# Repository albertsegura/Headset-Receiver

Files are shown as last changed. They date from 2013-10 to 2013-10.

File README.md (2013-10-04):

Headset-Receiver
================

Custom embedded Arduino board that provides Bluetooth/FM/Jack for a Headphones.
* Bluetooth rn-52 module
* Si4703 FM chip
* Arduino Pro mini 3.3v based board

Repository Contents
-------------------
* **/Eagle Files** - Eagle files for the two boards (.brd, .sch)

OSH PARK
--------
[Headset-Mainboard  
 *Main board*](http://oshpark.com/shared_projects/1vYQ7i1L)

[Headset-Mainboard  
 *Bluetooth Module*](http://oshpark.com/shared_projects/EPMXIzBB)

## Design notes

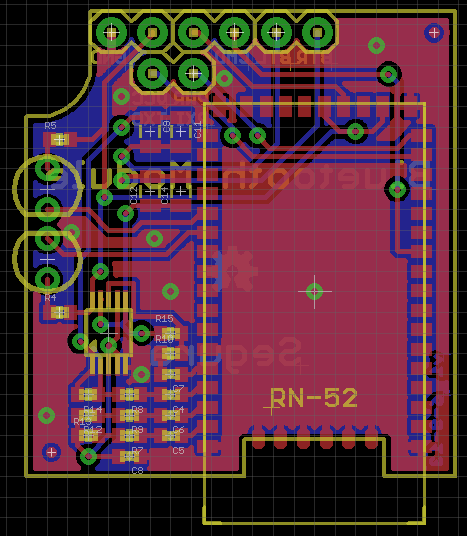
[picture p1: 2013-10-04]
Eagle Files/bluetooth-module.png

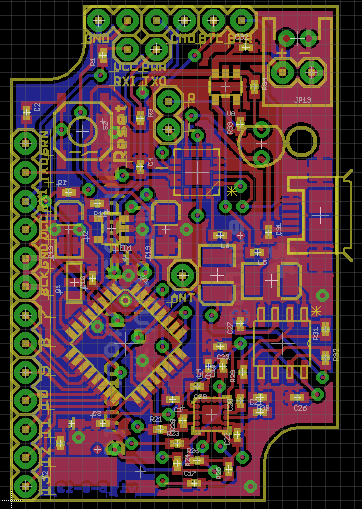
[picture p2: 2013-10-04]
Eagle Files/mainboard.png

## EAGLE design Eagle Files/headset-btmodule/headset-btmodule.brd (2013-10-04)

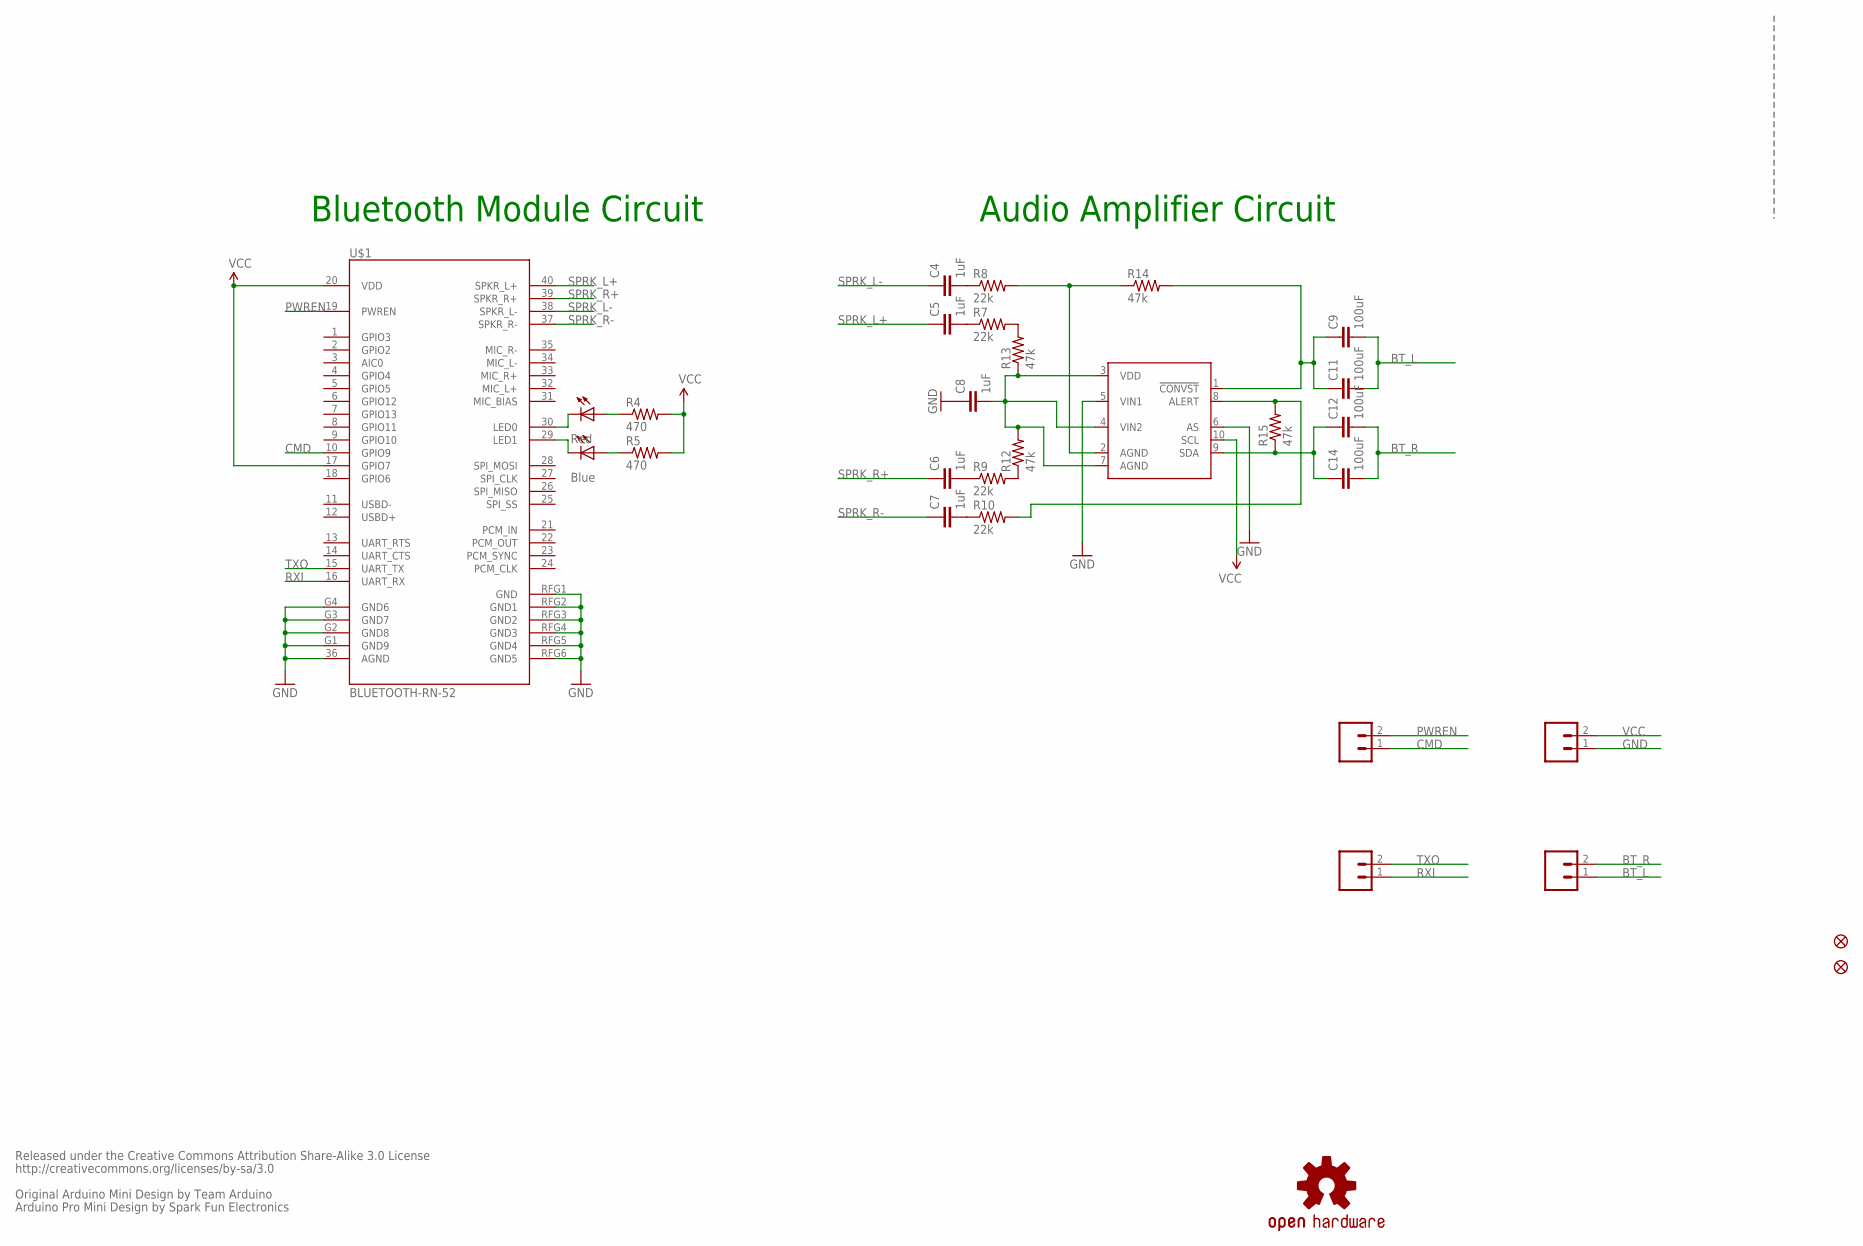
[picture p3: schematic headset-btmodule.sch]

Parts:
AUDIO: M02PTH; 1X02
C4, C5, C6, C7, C8: 1uF; 0402-CAP
C9, C11, C12, C14: 100uF; 0805
CMD: M02PTH; 1X02
JP5, JP8: FIDUCIALUFIDUCIAL; MICRO-FIDUCIAL
LED3: Red; LED3MM-NS
LED4: Blue; LED3MM-NS
POWER: M02PTH; 1X02
R4, R5: 470; 0402-RES
R7, R8, R9, R10: 22k; 0402-RES
R12, R13, R14, R15: 47k; 0402-RES
T: AD7992; MSOP10
TX: M02PTH; 1X02
U$1: BLUETOOTH-RN-52; RN-52
U$3: OSHW-LOGOS; OSHW-LOGO-S

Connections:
BT_L: AUDIO.1, C9.2, C11.2
BT_R: AUDIO.2, C12.2, C14.2
CMD: CMD.1, U$1.10 (GPIO9)
GND: C8.1, POWER.1, T.5 (VIN1), T.6 (AS), U$1.36 (AGND), U$1.G1 (GND9), U$1.G2 (GND8), U$1.G3 (GND7), U$1.G4 (GND6), U$1.RFG1 (GND), U$1.RFG2 (GND1), U$1.RFG3 (GND2), U$1.RFG4 (GND3), U$1.RFG5 (GND4), U$1.RFG6 (GND5)
unnamed: LED3.A, R4.1
unnamed: LED4.A, R5.1
unnamed: LED3.K (C), U$1.30 (LED0)
unnamed: LED4.K (C), U$1.29 (LED1)
unnamed: C12.1, C14.1, R15.1, T.9 (SDA)
unnamed: R10.2, R15.2, T.8 (ALERT)
unnamed: R7.2, R13.2
unnamed: C9.1, C11.1, R14.2, T.1 (!CONVST)
unnamed: R9.2, R12.1
unnamed: C6.2, R9.1
unnamed: C7.2, R10.1
unnamed: C5.2, R7.1
unnamed: C4.2, R8.1
unnamed: C8.2, R12.2, R13.1, T.3 (VDD), T.4 (VIN2), T.7 (AGND)
unnamed: R8.2, R14.1, T.2 (AGND)
PWREN: CMD.2, U$1.19 (PWREN)
RXI: TX.1, U$1.16 (UART_RX)
SPRK_L+: C5.1, U$1.40 (SPKR_L+)
SPRK_L-: C4.1, U$1.38 (SPKR_L-)
SPRK_R+: C6.1, U$1.39 (SPKR_R+)
SPRK_R-: C7.1, U$1.37 (SPKR_R-)
TXO: TX.2, U$1.15 (UART_TX)
VCC: POWER.2, R4.2, R5.2, T.10 (SCL), U$1.17 (GPIO7), U$1.20 (VDD)

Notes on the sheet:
Released under the Creative Commons Attribution Share-Alike 3.0 License
http://creativecommons.org/licenses/by-sa/3.0
Original Arduino Mini Design by Team Arduino
Arduino Pro Mini Design by Spark Fun Electronics
Bluetooth Module Circuit
Audio Amplifier Circuit

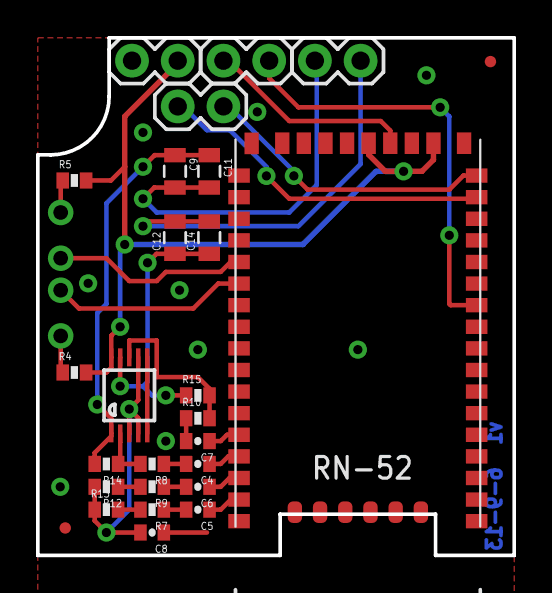
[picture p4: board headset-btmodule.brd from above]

Board: 2 copper layers, 26.5 x 28.8 mm, 30 parts (1 on the bottom side), 27 nets.

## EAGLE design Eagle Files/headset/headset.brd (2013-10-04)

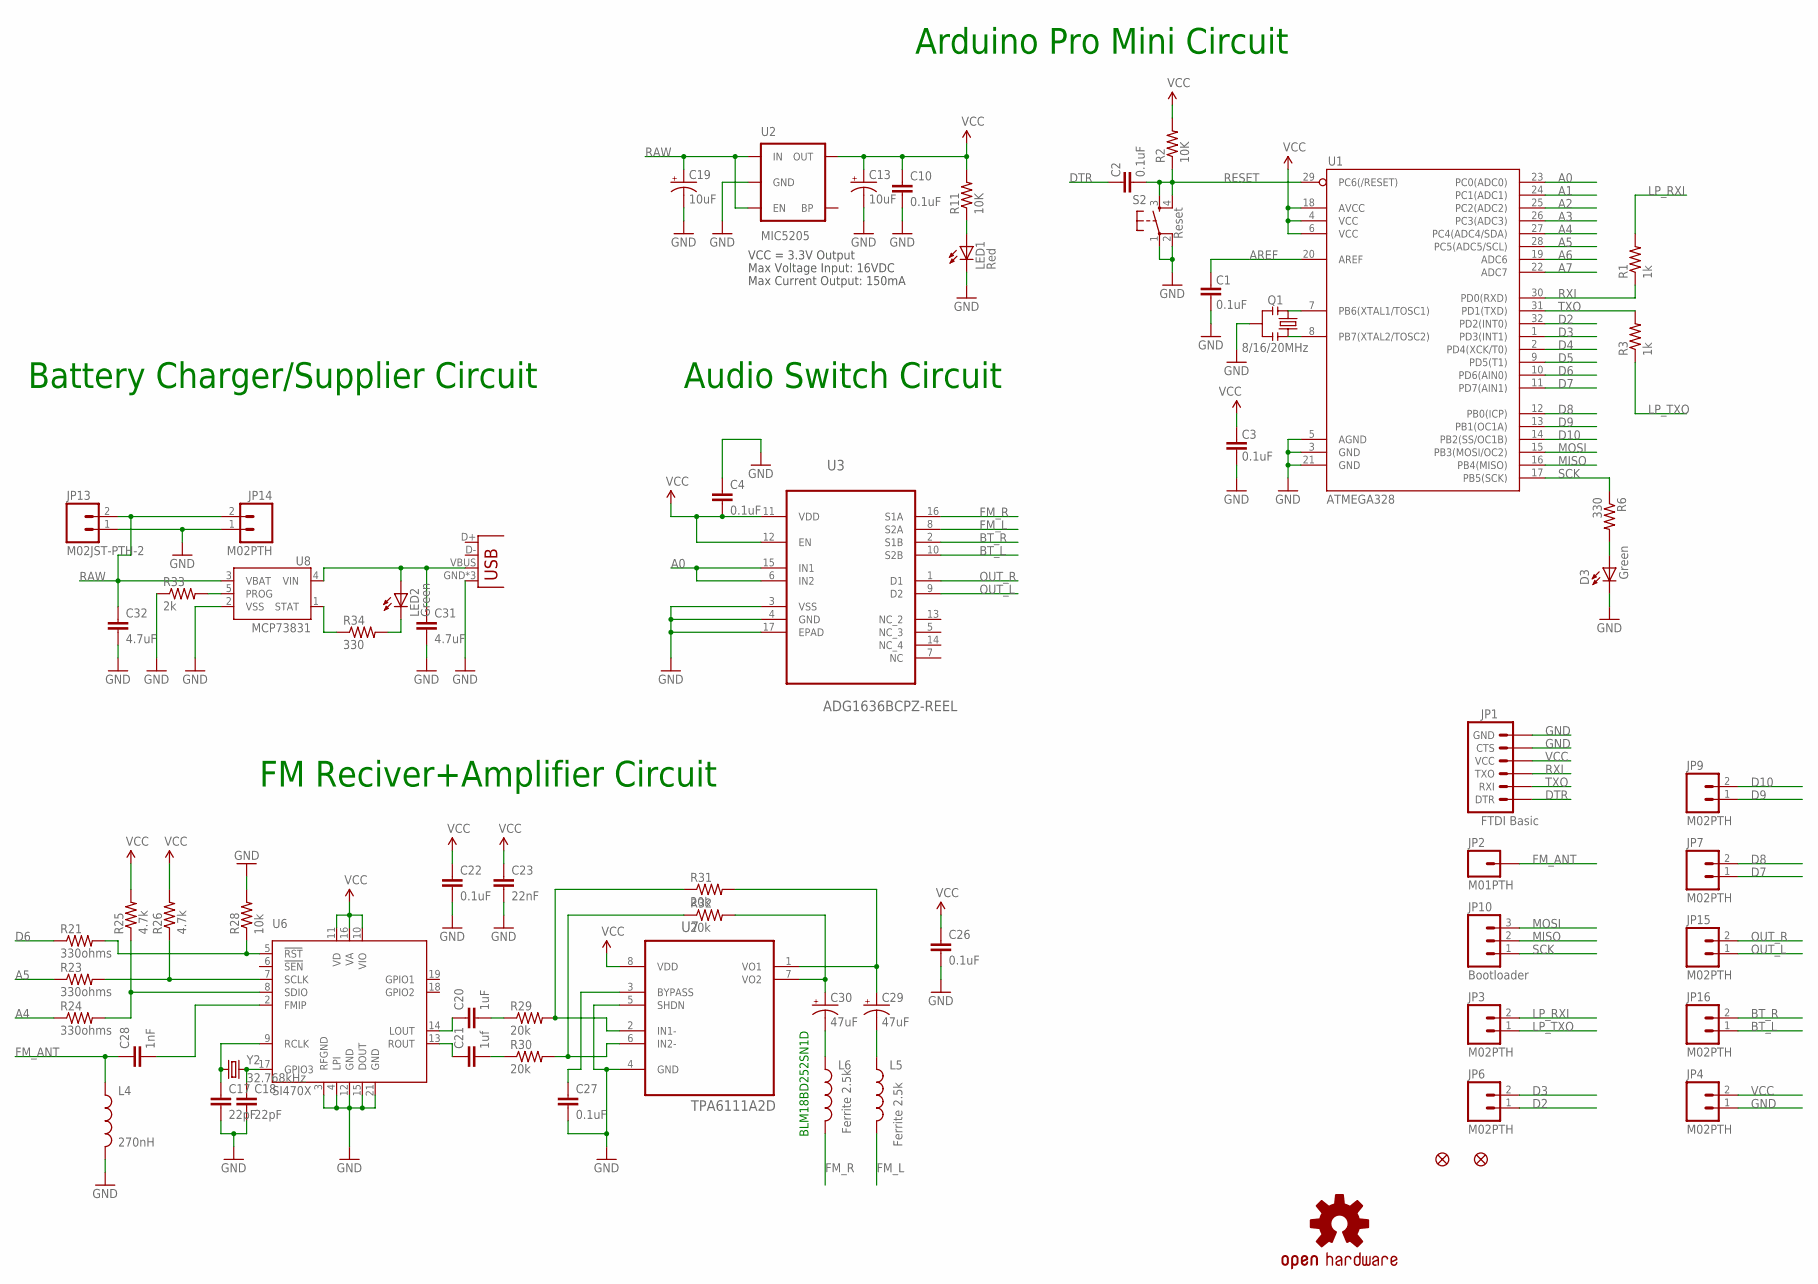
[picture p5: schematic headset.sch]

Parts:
C1, C2, C3, C4, C10, C22, C26, C27: 0.1uF; 0402-CAP
C13, C19: 10uF; EIA3216
C17, C18: 22pF; 0402-CAP
C20: 1uF; 0402-CAP
C21: 1uf; 0402-CAP
C23: 22nF; 0402-CAP
C28: 1nF; 0402-CAP
C29, C30: 47uF; EIA3528
C31, C32: 4.7uF; 0402-CAP
D3: Green; LED-0603
JP1: FTDI Basic; 1X06
JP2: M01PTH; 1X01
JP3, JP4, JP6, JP7, JP9, JP14, JP15, JP16: M02PTH; 1X02
JP5, JP8: FIDUCIALUFIDUCIAL; MICRO-FIDUCIAL
JP10: Bootloader; 1X03
JP12: USB-MICROB
JP13: M02JST-PTH-2; JST-2-PTH
L4: 270nH; C0402
L5, L6: Ferrite 2.5k; C0402
LED1: Red; LED-0603
LED2: Green; LED3MM-NS
Q1: 8/16/20MHz; RESONATOR-SMD
R1, R3: 1k; 0402-RES
R2, R11: 10K; 0402-RES
R6, R34: 330; 0402-RES
R21, R23, R24: 330ohms; 0402-RES
R25, R26: 4.7k; 0402-RES
R28: 10k; 0402-RES
R29, R30, R31, R32: 20k; 0402-RES
R33: 2k; 0402-RES
S2: Reset; TACTILE_SWITCH_SMD
U1: ATMEGA328; TQFP32-08
U2: MIC5205; SOT23-5
U3: ADG1636BCPZ-REEL; QFN65P400X400X100-17N
U6: SI470X
U7: TPA6111A2D; SOIC127P600X175-8N
U8: MCP73831; SOT23-5
U$3: OSHW-LOGOS; OSHW-LOGO-S
Y2: 32.768kHz; CRYSTAL-32KHZ-SMD

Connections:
A0: U1.23 (PC0(ADC0)), U3.6 (IN2), U3.15 (IN1)
A1: U1.24 (PC1(ADC1))
A2: U1.25 (PC2(ADC2))
A3: U1.26 (PC3(ADC3))
A4: R24.1, U1.27 (PC4(ADC4/SDA))
A5: R23.1, U1.28 (PC5(ADC5/SCL))
A6: U1.19 (ADC6)
A7: U1.22 (ADC7)
AREF: C1.2, U1.20 (AREF)
BT_L: JP16.1, U3.10 (S2B)
BT_R: JP16.2, U3.2 (S1B)
D2: JP6.1, U1.32 (PD2(INT0))
D3: JP6.2, U1.1 (PD3(INT1))
D4: U1.2 (PD4(XCK/T0))
D5: U1.9 (PD5(T1))
D6: R21.1, U1.10 (PD6(AIN0))
D7: JP7.1, U1.11 (PD7(AIN1))
D8: JP7.2, U1.12 (PB0(ICP))
D9: JP9.1, U1.13 (PB1(OC1A))
D10: JP9.2, U1.14 (PB2(SS/OC1B))
DTR: C2.2, JP1.1 (DTR)
FM_ANT: C28.1, JP2.1, L4.1
FM_L: L5.2, U3.8 (S2A)
FM_R: L6.2, U3.16 (S1A)
GND: C1.1, C3.1, C4.1, C10.2, C13.C (-), C17.2, C18.2, C19.C (-), C22.2, C23.2, C26.2, C27.2, C31.2, C32.2, D3.C, JP1.5 (CTS), JP1.6 (GND), JP4.1, JP12.GND, JP12.MT1 (GND), JP12.MT2 (GND), JP13.1, JP14.1, L4.2, LED1.C, Q1.2, R28.2, R33.1, S2.1, S2.2, U1.3 (GND), U1.5 (AGND), U1.21 (GND), U2.2 (GND), U3.3 (VSS), U3.4 (GND), U3.17 (EPAD), U6.3 (RFGND), U6.4 (LPI), U6.12 (GND), U6.15 (DOUT), U6.21 (GND), U7.4 (GND), U7.5 (SHDN), U8.2 (VSS)
LP_RXI: JP3.2, R1.2
LP_TXO: JP3.1, R3.1
MISO: JP10.2, U1.16 (PB4(MISO))
MOSI: JP10.3, U1.15 (PB3(MOSI/OC2))
unnamed: Q1.1, U1.8 (PB7(XTAL2/TOSC2))
unnamed: Q1.3, U1.7 (PB6(XTAL1/TOSC1))
unnamed: D3.A, R6.2
unnamed: R21.2, R28.1, U6.5 (!RST)
unnamed: R23.2, R26.1, U6.7 (SCLK)
unnamed: R24.2, R25.1, U6.8 (SDIO)
unnamed: C28.2, U6.2 (FMIP)
unnamed: C20.1, U6.14 (LOUT)
unnamed: C20.2, R29.1
unnamed: R29.2, R31.1, U7.2 (IN1-)
unnamed: R30.2, R32.1, U7.6 (IN2-)
unnamed: C21.2, R30.1
unnamed: C21.1, U6.13 (ROUT)
unnamed: C27.1, U7.3 (BYPASS)
unnamed: LED1.A, R11.1
unnamed: C29.A (+), R31.2, U7.1 (VO1)
unnamed: C30.A (+), R32.2, U7.7 (VO2)
unnamed: C17.1, U6.9 (RCLK), Y2.X1 (1)
unnamed: C18.1, U6.17 (GPIO3), Y2.X2 (2)
unnamed: C29.C (-), L5.1
unnamed: C30.C (-), L6.1
unnamed: C31.1, JP12.VBUS, LED2.A, U8.4 (VIN)
unnamed: LED2.K (C), R34.2
unnamed: R34.1, U8.1 (STAT)
unnamed: R33.2, U8.5 (PROG)
OUT_L: JP15.1, U3.9 (D2)
OUT_R: JP15.2, U3.1 (D1)
RAW: C19.A (+), C32.1, JP13.2, JP14.2, U2.1 (IN), U2.3 (EN), U8.3 (VBAT)
RESET: C2.1, R2.1, S2.3, S2.4, U1.29 (PC6(/RESET))
RXI: JP1.3 (TXO), R1.1, U1.30 (PD0(RXD))
SCK: JP10.1, R6.1, U1.17 (PB5(SCK))
TXO: JP1.2 (RXI), R3.2, U1.31 (PD1(TXD))
VCC: C3.2, C4.2, C10.1, C13.A (+), C22.1, C23.1, C26.1, JP1.4 (VCC), JP4.2, R2.2, R11.2, R25.2, R26.2, U1.4 (VCC), U1.6 (VCC), U1.18 (AVCC), U2.5 (OUT), U3.11 (VDD), U3.12 (EN), U6.10 (VIO), U6.11 (VD), U6.16 (VA), U7.8 (VDD)

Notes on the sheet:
Max Voltage Input: 16VDC
Max Current Output: 150mA
VCC = 3.3V Output
BLM18BD252SN1D
FM Reciver+Amplifier Circuit
Battery Charger/Supplier Circuit
Audio Switch Circuit
Arduino Pro Mini Circuit

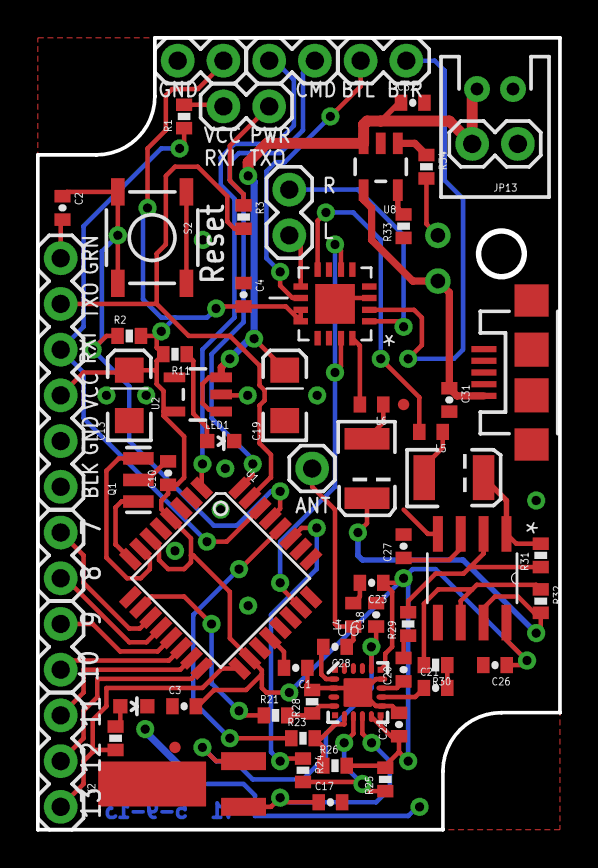
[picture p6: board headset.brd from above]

Board: 2 copper layers, 29.0 x 44.0 mm, 68 parts (1 on the bottom side), 55 nets.

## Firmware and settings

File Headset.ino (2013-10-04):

#include "Si4703_Breakout.h"
#include "RN52_BTModule.h"
#include <Wire.h>


/****** PIN CONFIGURATION ******/
//>Bluetooth
const uint8_t BT_PWREN         = 2;
const uint8_t BT_CMD           = 3;

//>FM radio
const uint8_t SDIO             = A4;
const uint8_t SCLK             = A5;
const uint8_t resetPin         = 6;

//>Buttons
const uint8_t UPPushbuttonPin  = 7;
const uint8_t MIDPushbuttonPin = 8;
const uint8_t DWNPushbuttonPin = 9;

//const uint8_t BT_FMSwitchPin   = 10; //Not in use
const uint8_t AUDIOSelectorPin = A0;


/****** BUTTON DEBOUNCING ******/
uint8_t buttonState[3]         = {HIGH,HIGH,HIGH};
uint8_t lastButtonState[3]     = {HIGH,HIGH,HIGH};
long lastDebounceTime[3]       = {0,0,0};
long buttonTimePushed[3]       = {0,0,0};
const long debounceDelay       = 50;
const uint16_t pushedButtonTime = 500;


const uint8_t FMModule         = 0;
const uint8_t BTModule         = 1;
const uint8_t FMAndroid        = 2;
uint8_t AudioMode              = FMModule;
uint16_t defaultRadio          = 877;

RN52_BTModule       bluetooth(BT_PWREN, BT_CMD);
Si4703_Breakout     radio(resetPin, SDIO, SCLK);


char rdsBuffer[32];



void setup() {
    
    pinMode(UPPushbuttonPin,  INPUT_PULLUP);
    pinMode(MIDPushbuttonPin, INPUT_PULLUP);
    pinMode(DWNPushbuttonPin, INPUT_PULLUP);
    pinMode(AUDIOSelectorPin, OUTPUT);
    digitalWrite(AUDIOSelectorPin, HIGH);
    
    Serial.begin(115200);
    Serial.println("\n\nSi4703_Breakout Test Sketch");
    Serial.println("===========================");  
    Serial.println("a b     Favourite stations");
    Serial.println("+ -     Volume (max 15)");
    Serial.println("u d     Seek up / down");
    Serial.println("r       Listen for RDS Data (15 sec timeout)");
    Serial.println("Send me a command letter.");
    bluetooth.powerOn();
    //radio.powerOn();
    //radio.setChannel(defaultRadio);
    Serial.println("FM Module Enabled");
}




void pushbuttonUP(unsigned char option) {
    Serial.print("Released: [0]"), Serial.print(" Time: "), Serial.println(buttonTimePushed[0]);
    
    if (option == 0) {
        if (AudioMode == FMModule) {
            radio.increaseVolume();
            if (radio.isMuted()) radio.toggleMute();
        }
        else if (AudioMode == BTModule) {
            bluetooth.increseVolume();
        }
        else if (AudioMode == FMAndroid) {
            
        }
    }
    else if (option == 1) {
        if (AudioMode == FMModule) {
            radio.seekUp();
            if (radio.isMuted()) radio.toggleMute();
        }
        else if (AudioMode == BTModule) {
            bluetooth.nextTrack();
        }
        else if (AudioMode == FMAndroid) {
            
        }
    }
}

void pushbuttonMID(unsigned char option) {
    Serial.print("Released: [1]"), Serial.print(" Time: "), Serial.println(buttonTimePushed[1]);
    
    if (option == 0) {
        if (AudioMode == FMModule) {
          //Serial.println("RDS listening");
          //radio.readRDS(rdsBuffer, 15000);
          //Serial.print("RDS heard:");
          //Serial.write((uint8_t*)rdsBuffer,32);
          radio.toggleMute();
        }
        else if (AudioMode == BTModule) {
            bluetooth.togglePause();
        }
        else if (AudioMode == FMAndroid) {
            bluetooth.togglePause();
        }
    }
    else if (option == 1) {
        if (AudioMode == FMModule) {
            AudioMode = BTModule;
            Serial.print("PowerDown Radio: ");
            radio.powerOff(); //delay(1500);
            Serial.println("Done");
            
            digitalWrite(AUDIOSelectorPin, HIGH);
            
            Serial.print("PowerOn Bt: ");
            bluetooth.powerOn();
            Serial.println("Done");
            
        }
        else if (AudioMode == BTModule) {
            AudioMode = FMAndroid;
            
            digitalWrite(AUDIOSelectorPin, LOW);
            
            Serial.print("PowerOn Radio: ");
            radio.powerOn();
            Serial.println("Done");
            radio.setChannel(defaultRadio);
        }
        else if (AudioMode == FMAndroid) {
            AudioMode = FMModule;
            Serial.print("PowerDown Bt: ");
            bluetooth.powerOff();
            Serial.println("Done");
            
            digitalWrite(AUDIOSelectorPin, LOW);
            
        }
    }
}

void pushbuttonDWN(unsigned char option) {
    Serial.print("Released: [2]"), Serial.print(" Time: "), Serial.println(buttonTimePushed[2]);
    
    if (option == 0) {
        if (AudioMode == FMModule) {
            radio.decreaseVolume();
            if (radio.isMuted()) radio.toggleMute();
        }
        else if (AudioMode == BTModule) {
            bluetooth.decreaseVolume();
        }
        else if (AudioMode == FMAndroid) {
            
        }
    }
    else if (option == 1) {
        if (AudioMode == FMModule) {
            radio.seekDown();
            if (radio.isMuted()) radio.toggleMute();
        }
        else if (AudioMode == BTModule) {
            bluetooth.previousTrack();
        }
        else if (AudioMode == FMAndroid) {
            
        }
    }
}


void testButtons() {
    uint8_t reading;
    uint8_t released[3] = {0,0,0};
    uint8_t button = UPPushbuttonPin;
    
    for (uint8_t i=0; i < 3; i++, button++) {
        reading = digitalRead(button);
        
        if (reading != lastButtonState[i]) {
            lastDebounceTime[i] = millis();
        }
        
        long time = millis();
        if ((time-lastDebounceTime[i]) > debounceDelay) {
            if(reading != buttonState[i]) {
                buttonState[i] = reading;
                if (reading) {
                    buttonTimePushed[i] = time-buttonTimePushed[i];
                    released[i] = 1;
                }
                else buttonTimePushed[i] = time;
                Serial.print("Button: [");
                Serial.print(i);
                Serial.print("] State: ");
                Serial.println((int)reading);
            }
        }
        lastButtonState[i] = reading;
    }
    
    if (released[0])      released[0] = 0, pushbuttonUP(buttonTimePushed[0] >= pushedButtonTime);
    else if (released[1]) released[1] = 0, pushbuttonMID(buttonTimePushed[1] >= pushedButtonTime);
    else if (released[2]) released[2] = 0, pushbuttonDWN(buttonTimePushed[2] >= pushedButtonTime);
}

void testSerial() {
    // Comunication with bluetooth module/Android via bluetooth link
    
}

void loop() {
    testButtons();
    testSerial();
}



/*
void displayInfo() {
   Serial.print("Channel:"); Serial.print(channel); 
   Serial.print(" Volume:"); Serial.println(volume); 
}

  Serial.println("RDS listening");
  radio.readRDS(rdsBuffer, 15000);
  Serial.print("RDS heard:");
  Serial.println(rdsBuffer);
*/

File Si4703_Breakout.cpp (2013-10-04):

/*

	See changelog.

*/

#include "Arduino.h"
#include "Si4703_Breakout.h"
#include "Wire.h"

Si4703_Breakout::Si4703_Breakout(uint8_t resetPin, uint8_t sdioPin, uint8_t sclkPin)
{
	_resetPin = resetPin;
	_sdioPin = sdioPin;
	_sclkPin = sclkPin;
	_poweredDown = false;

	// Default EUROPE, overwrite later on powerOn function.
	_fmL = 875;
	_fmS = 1;
}

void Si4703_Breakout::powerOn()
{
	if (!_poweredDown) si4703_init();
	else rePowerOn();
}

void Si4703_Breakout::powerOff()
{
	// Si4702/03-C19, Section 4.11, page 20
	// AN230 - Low Power, Bus Accessible - 2.1.2 page 5-6
	readRegisters();

	si4703_registers[SYSCONFIG1] |= (1<<GPIO21);            // GPIOX set to (Low-0x10), to reduce current consumption:
	si4703_registers[SYSCONFIG1] &= ~(1<<GPIO20);           // AN230 Table 4- Powerdown Sequence
	si4703_registers[SYSCONFIG1] |= (1<<GPIO11);            // GPIO3 not set because it mess up XOSCEN
	si4703_registers[SYSCONFIG1] &= ~(1<<GPIO10);

	si4703_registers[POWERCFG] &= ~(1<<DMUTE); 				// Mute enabled
	si4703_registers[TEST1] |= (1<<AHIZEN);                 // Enable AHIZEN (opt)
	si4703_registers[SYSCONFIG1] &= ~(1<<RDS);              // Disable RDS
	si4703_registers[POWERCFG] |= (1<<ENABLE);       	  	// Enable to 1
	si4703_registers[POWERCFG] |= (1<<DISABLE);				// Disable to 1

	updateRegisters();

	delay(2); 	// 1.5 ms max until the device powers down (enable and disable set to 0)
				// AN230 - Figure 9. Powerdown Timing

	_poweredDown = true;
}

void Si4703_Breakout::rePowerOn()
{
	// Si4702/03-C19, Section 4.11, page 21
	// AN230 - Low Power, Bus Accessible - 2.1.2 page 5-6
	readRegisters();

	si4703_registers[POWERCFG] |= (1<<DMUTE);				// Mute disabled
	si4703_registers[TEST1] &= ~(1<<AHIZEN);				// Disable AHIZEN (opt)
	si4703_registers[SYSCONFIG1] |= (1<<RDS);				// Enable RDS
	si4703_registers[POWERCFG] |= (1<<ENABLE);				// Enable to 1
	si4703_registers[POWERCFG] &= ~(1<<DISABLE);			// Disable to 0

	updateRegisters();
}

// 31 Volume levels AN230 - 3.3.3. VOLEXT
void Si4703_Breakout::setVolume(uint8_t volume)
{
	boolean setLowRange = false;
	setLowRange = (volume < 16);
	if (volume > 30) volume = 15;
	if (volume > 15) volume -= 15;

	readRegisters(); // Read the current register set
	
	si4703_registers[SYSCONFIG2] &= 0xFFF0; // Clear volume bits
	si4703_registers[SYSCONFIG2] |= volume; // Set new volume
	if (setLowRange) si4703_registers[SYSCONFIG3] |= (1 << VOLEXT);
	else si4703_registers[SYSCONFIG3] &= ~(1 << VOLEXT);

	updateRegisters(); // Update
}

uint8_t Si4703_Breakout::getVolume()
{
	readRegisters();
	boolean lowRange = (si4703_registers[SYSCONFIG3] & (1 << VOLEXT));
	uint8_t volume = (si4703_registers[SYSCONFIG2] & 0x000F);
	if (!lowRange) volume+=15; // Upper range
	return volume;
}

// 31 Volume levels
uint8_t Si4703_Breakout::increaseVolume()
{
	readRegisters();
	uint8_t volume = (si4703_registers[SYSCONFIG2] & 0x000F);
	++volume;
	if (volume > 15) {
		if (si4703_registers[SYSCONFIG3] & (1 << VOLEXT)) {
			si4703_registers[SYSCONFIG3] &= ~(1 << VOLEXT);
			volume = 1;
		}
		else volume = 15;
	}
	si4703_registers[SYSCONFIG2] &= 0xFFF0; // Clear volume bits
	si4703_registers[SYSCONFIG2] |= volume; // Set new volume

	updateRegisters();

	return volume;
}

// 31 Volume levels
uint8_t Si4703_Breakout::decreaseVolume() 
{
	readRegisters();

	uint8_t volume = (si4703_registers[SYSCONFIG2] & 0x000F);
	--volume;
	if (volume == 255 || volume == 0) {
		if (si4703_registers[SYSCONFIG3] & (1 << VOLEXT)) volume = 0;
		else {
			si4703_registers[SYSCONFIG3] |= (1 << VOLEXT);
			volume = 15;
		}
	}
	si4703_registers[SYSCONFIG2] &= 0xFFF0; // Clear volume bits
	si4703_registers[SYSCONFIG2] |= volume; // Set new volume

	updateRegisters();

	return volume;
}

boolean Si4703_Breakout::toggleMute() 
{
	readRegisters();
	si4703_registers[POWERCFG] ^= (1<<DMUTE);
	updateRegisters();

	return isMuted();
}

boolean Si4703_Breakout::isMuted() 
{
	return !(si4703_registers[POWERCFG] & (1<<DMUTE));
}

//To get the Si4703 inito 2-wire mode, SEN needs to be high and SDIO needs to be low after a reset
//The breakout board has SEN pulled high, but also has SDIO pulled high. Therefore, after a normal power up
//The Si4703 will be in an unknown state. RST must be controlled
void Si4703_Breakout::si4703_init()
{
	pinMode(_resetPin, OUTPUT);
	pinMode(_sdioPin, OUTPUT); //SDIO is connected to A4 for I2C
	digitalWrite(_sdioPin, LOW); //A low SDIO indicates a 2-wire interface
	digitalWrite(_resetPin, LOW); //Put Si4703 into reset
	delay(1); //Some delays while we allow pins to settle
	digitalWrite(_resetPin, HIGH); //Bring Si4703 out of reset with SDIO set to low and SEN pulled high with on-board resistor
	delay(1); //Allow Si4703 to come out of reset

	Wire.begin(); //Now that the unit is reset and I2C inteface mode, we need to begin I2C

	readRegisters();
	si4703_registers[TEST1] = 0x8100; //Enable the oscillator, from AN230 page 12, rev 0.9
	updateRegisters();

	delay(600); //Wait for clock to settle 500 min - from AN230 page 12

	readRegisters();

	si4703_registers[POWERCFG] |= (1<<ENABLE); //Enable bit to 1
	si4703_registers[POWERCFG] &= ~(1<<DISABLE); //Disable bit to 0
	si4703_registers[POWERCFG] |= (1<<DMUTE); //Disable Mute
	si4703_registers[SYSCONFIG1] |= (1<<RDS); //Enable RDS
	si4703_registers[POWERCFG] &= ~(1<<RDSM1); // RDS Standard, no verbose

	updateRegisters();
	delay(110); //Max powerup time, from datasheet (Table 8. FM Receiver Characteristics), page 13
	readRegisters();

	#if defined(EUROPE)
	si4703_registers[SYSCONFIG1] |= (1<<DE); //50micros Europe/Japan setup
	si4703_registers[SYSCONFIG2] &= ~(1<<BAND1); //87.5 - 108 Mhz (US/Europe) (Default)
	si4703_registers[SYSCONFIG2] &= ~(1<<BAND0); //87.5 - 108 Mhz (US/Europe) (Default)
	si4703_registers[SYSCONFIG2] &= ~(1<<SPACE1); //100kHz channel spacing for Europe/Japan
	si4703_registers[SYSCONFIG2] |= (1<<SPACE0); //100kHz channel spacing for Europe/Japan
	_fmL = 875;
	_fmS = 1;
	#endif

	#if defined(USA)
	si4703_registers[SYSCONFIG1] &= ~(1<<DE); //75micros USA/Australia setup
	si4703_registers[SYSCONFIG2] &= ~(1<<BAND1); //87.5 - 108 Mhz (US/Europe) (Default)
	si4703_registers[SYSCONFIG2] &= ~(1<<BAND0); //87.5 - 108 Mhz (US/Europe) (Default)
	si4703_registers[SYSCONFIG2] &= ~(1<<SPACE1); //100kHz channel spacing for US
	si4703_registers[SYSCONFIG2] &= ~(1<<SPACE0); //100kHz channel spacing for US
	_fmL = 875;
	_fmS = 2;
	#endif

	#if defined(JAPAN)
	si4703_registers[SYSCONFIG1] |= (1<<DE); //50micros Europe/Japan setup
	si4703_registers[SYSCONFIG2] &= ~(1<<BAND1); //76 - 108 Mhz (Japan wide range)
	si4703_registers[SYSCONFIG2] |= (1<<BAND0); //76 - 108 Mhz (Japan wide range)
	si4703_registers[SYSCONFIG2] &= ~(1<<SPACE1); //100kHz channel spacing for Europe/Japan
	si4703_registers[SYSCONFIG2] |= (1<<SPACE0); //100kHz channel spacing for Europe/Japan
	_fmL = 760;
	_fmS = 1;
	#endif
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

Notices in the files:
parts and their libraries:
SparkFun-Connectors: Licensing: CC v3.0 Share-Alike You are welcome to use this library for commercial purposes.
